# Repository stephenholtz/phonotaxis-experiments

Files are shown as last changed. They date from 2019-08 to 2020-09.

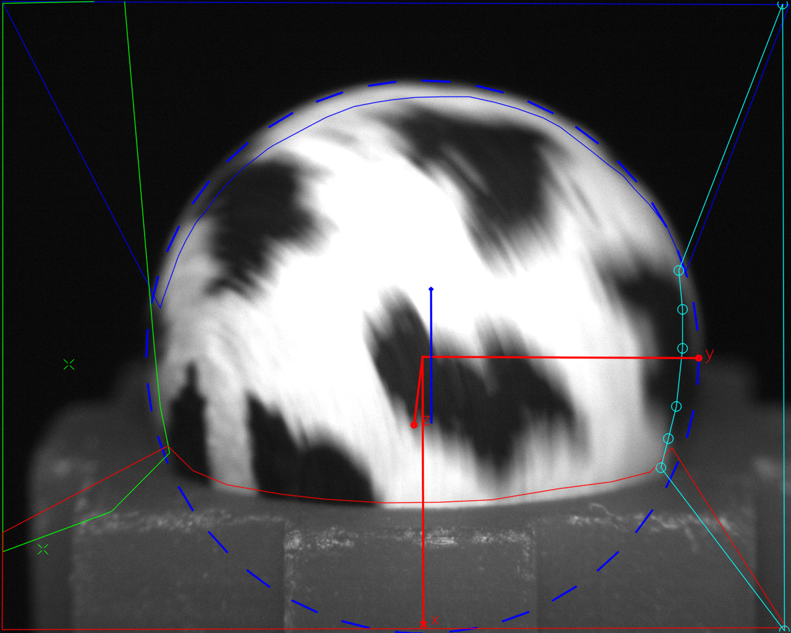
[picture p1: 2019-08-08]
config/fictrac-configImg.png

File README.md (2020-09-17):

phonotaxis-experiments
===
This repository contains code and support files to run a series of phonotaxis experiments. This documentation is quite sparse currently, but `./config` and `./docs` folders contain a large amount of useful information. Additionally, `./literature` has a large number of papers that may be useful to peruse. 

#### Sound Stimuli
There are 8 speakers currently installed in a ring around the center of the rig. Each speaker can be driven independently thanks to an 8 channel sound card. Note that not all speakers are likely able to deliver the same sound field properties to the animal due to some of the optomechanical elements installed to hold hardware. 

#### Cameras
The phonotaxis rig is currently equipped with two cameras. One camera is positioned behind an air supported ball for use with FicTrac offline (or online) tracking. The second camera is positioned above the animal to track additional behavioral responses and kinematic features, for example limb position (e.g. grooming bouts) and antennal movements. 

Since responses can be quite transient, especially at low temporal resolution, dropping frames is a large concern. The system has been stress tested to acquire _at least_ 100fps from both cameras with 2x2 binning using externally sent triggers for each frame from MATALB. The following settings inside of the SpinView GUI or hardware configuration were used. I have roughly categorized the settings to help direct future tinkering.

Hardware Configuration:
- Power both cameras with 12V power supplies directly from FLIR.
- Acquired both via a FLIR (PtGrey) supplied USB3 PCIe card
- Acquired over a FLIR supplied locking USB3.1 cables and active extenders Amazon Basics brand
- Frames written to an NVMI drive 

Triggering Settings to use the optically isolated input to trigger a frame acquisition, and the programmable pin to read out when frame exposures are happening.
- Continusous aquisition mode
- Exposure Mode = timed
- Exposure Auto = Off
- Set the exposure to something that looks good on the display (in units of microseconds)
- Gain Auto = Off
- Trig Sel = frame start
- Trig mode = on
- Trig act = rising
- Trig overlap = read out (not clear this is required)
- Line 2 
	- mode = output 
	- exposure
	- leave inverted unchecked (personal preference)

Acquisition Performance Settings:
- Use Buffered Acquisition
- Buffer Handling Mode should be set to Oldest First (this is very important!!!)
- Set SpinView priority to realtime in Windows 10
- Turn off draw image OR limit the dispayed FPS (settings accessed by right clicking on images)
- Change the Device Link Throuput setting
     - To determine a conservative/valid setting, lower the value until the displayed max FPS decreases in the GUI, then increase it a bit. 
- Bin at 2x (this may not be required)

#### Misc. Notes
- The computer is high performance, so your mileage may vary with older or less powerful machines.

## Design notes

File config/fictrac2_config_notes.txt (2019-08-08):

- Installed CMake
- Visual Studio 2017 Community Edition (needed to jump through many hoops to download) with C++ options selected
- vcpkg downloaded, and "integrated" printed the following afterwards:
	CMake projects should use: "-DCMAKE_TOOLCHAIN_FILE=C:/code/vcpkg/scripts/buildsystems/vcpkg.cmake"
- used vcpkg to install OpenCV, NLopt and Boost::asio packages as described inthe install guide:
	.\vcpkg install opencv[ffmpeg]:x64-windows nlopt:x64-windows boost-asio:x64-windows
	took about 20 mins
- since I am using spinnaker SDK for pointgrey cameras I ran this:
	cmake -G "Visual Studio 15 2017 Win64" -DCMAKE_TOOLCHAIN_FILE=C:/code/vcpkg/scripts/buildsystems/vcpkg.cmake -D PGR_USB3=ON -D PGR_DIR="C:\Program Files\Point Grey Research\Spinnaker" ..
- then to build I used:
	cmake --build . --config Release -j 4

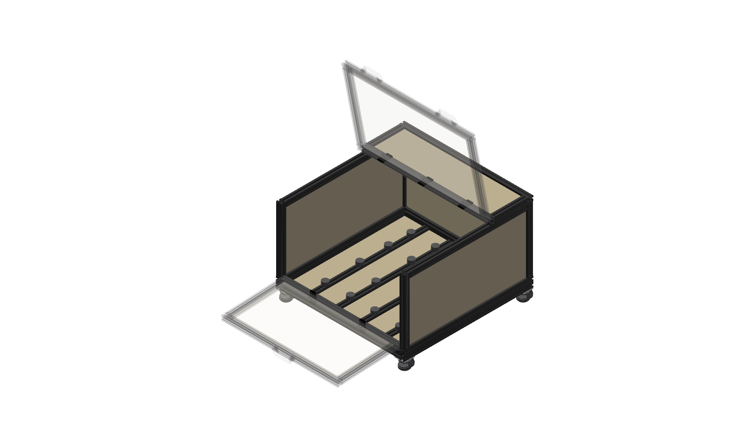
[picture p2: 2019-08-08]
design-files/enclosure/enclosure.png

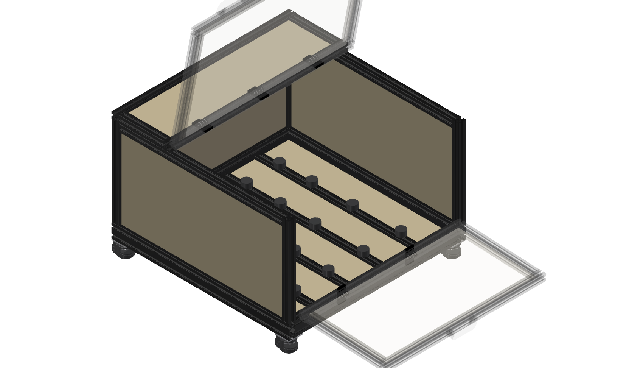
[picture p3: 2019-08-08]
design-files/enclosure/enclosure-zoom.png

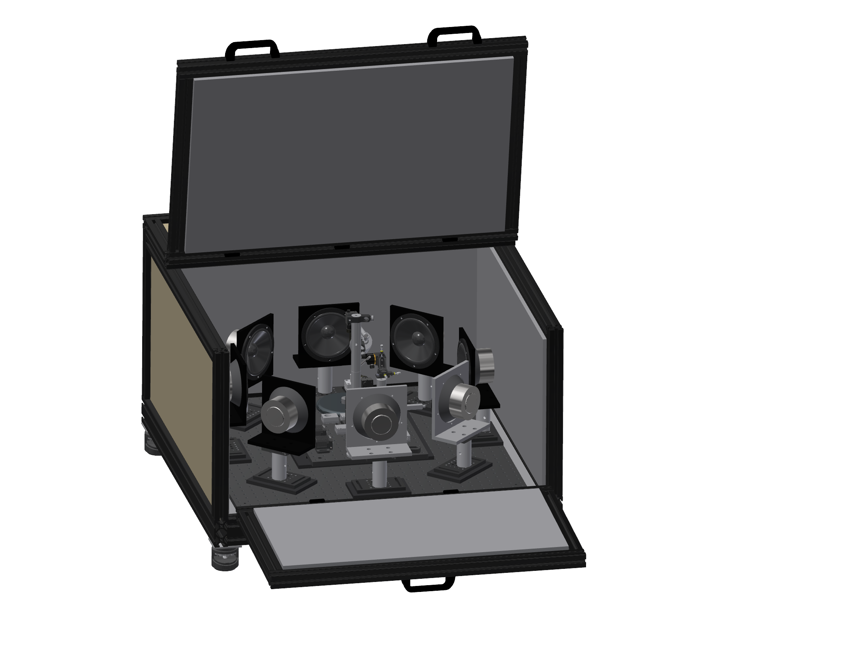
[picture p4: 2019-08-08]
design-files/auditory-behavior-rig.png

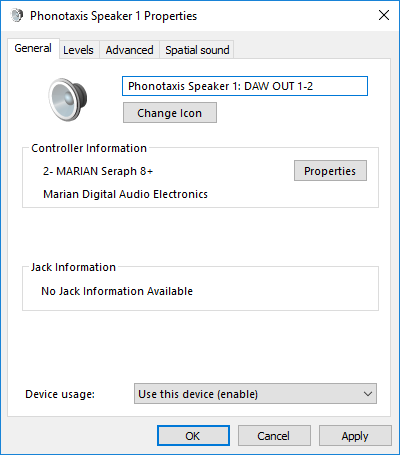
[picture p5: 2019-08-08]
config/speaker_general_windows_properties.png

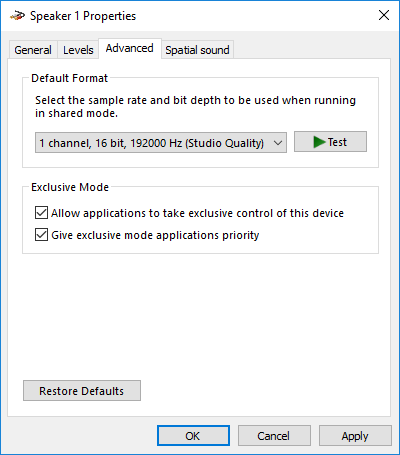
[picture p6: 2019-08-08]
config/speaker_advanced_windows_properties.png

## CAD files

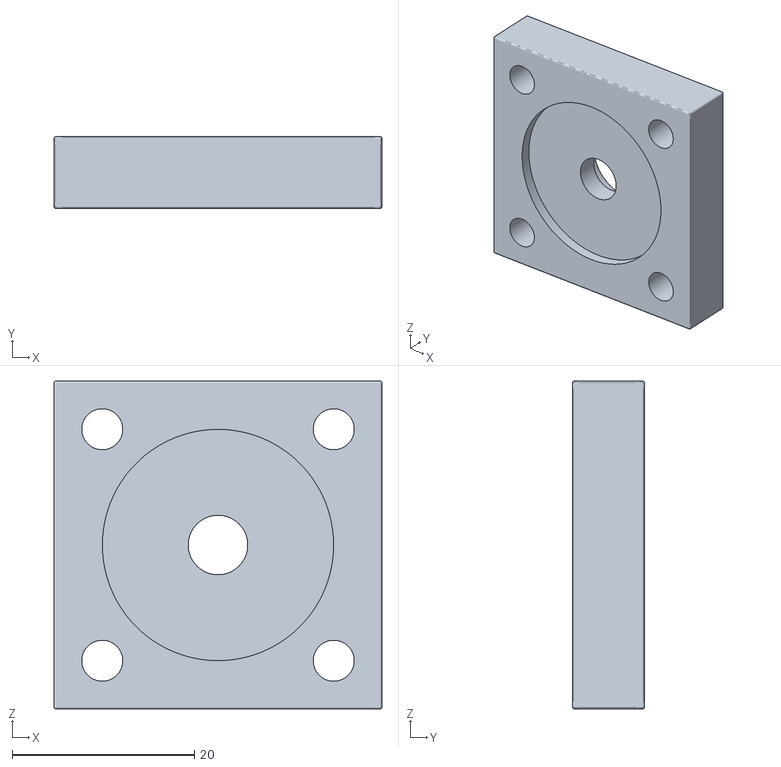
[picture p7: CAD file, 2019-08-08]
design-files/ball-assembly/ball-holder-to-post-adapter.stl
36.0 x 7.94 x 36.0

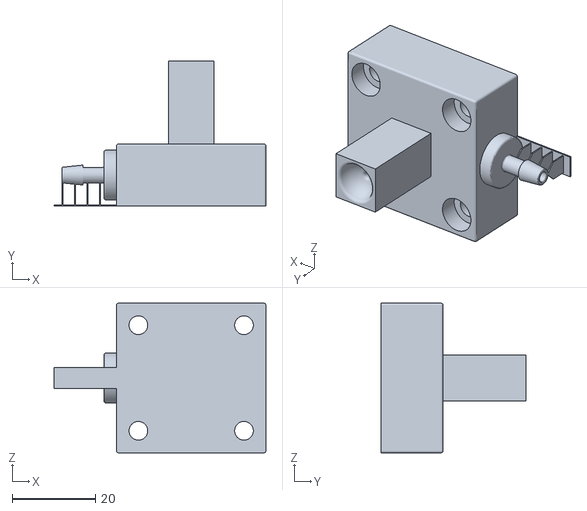
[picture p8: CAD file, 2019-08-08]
design-files/ball-holder/v01_top_square_side_barb_9mm/9mm_ball_holder_v01_manual_supports_mm_high_res.stl
51.0 x 35.0 x 36.0

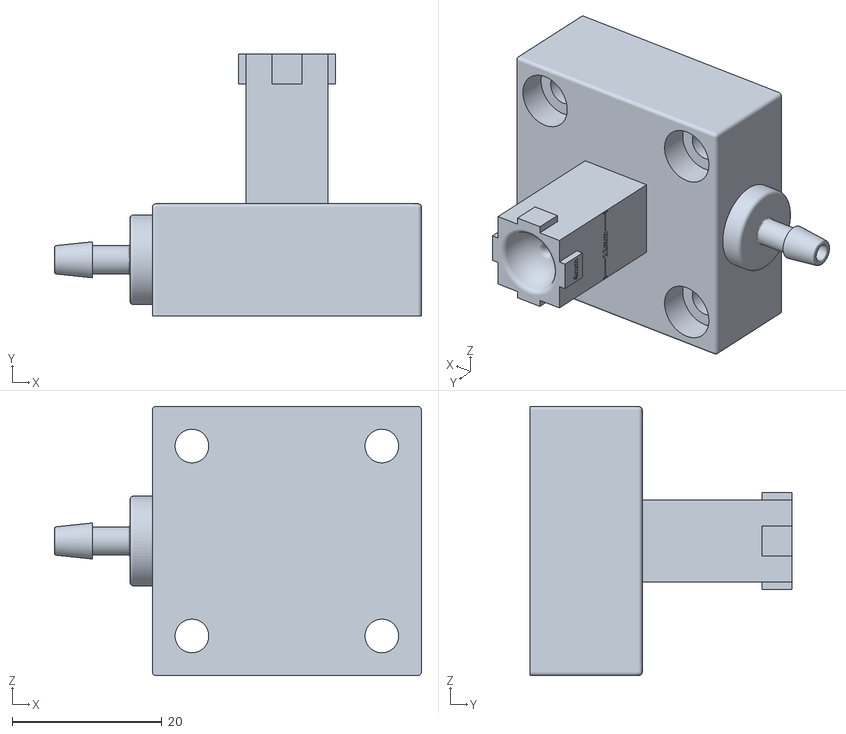
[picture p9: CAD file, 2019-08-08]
design-files/ball-holder/v02_top_side_squares/ball_holder_9mm_sidebarb_v02_mm.stl
49.1 x 35.0 x 36.0

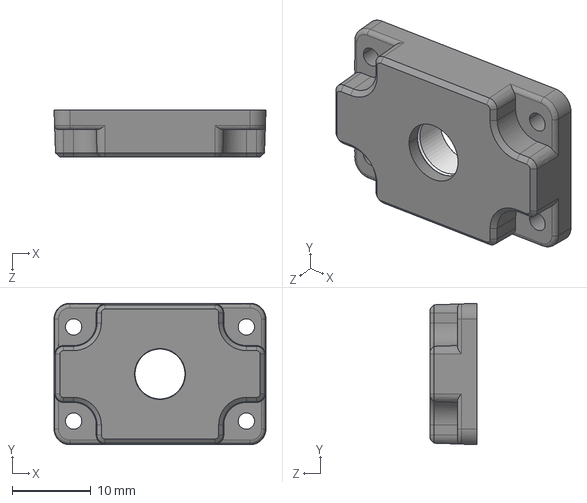
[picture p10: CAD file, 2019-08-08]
design-files/camera-assembly/Flea2 Tripod Adapter.IGS
27.0 x 18.0 x 5.99 mm

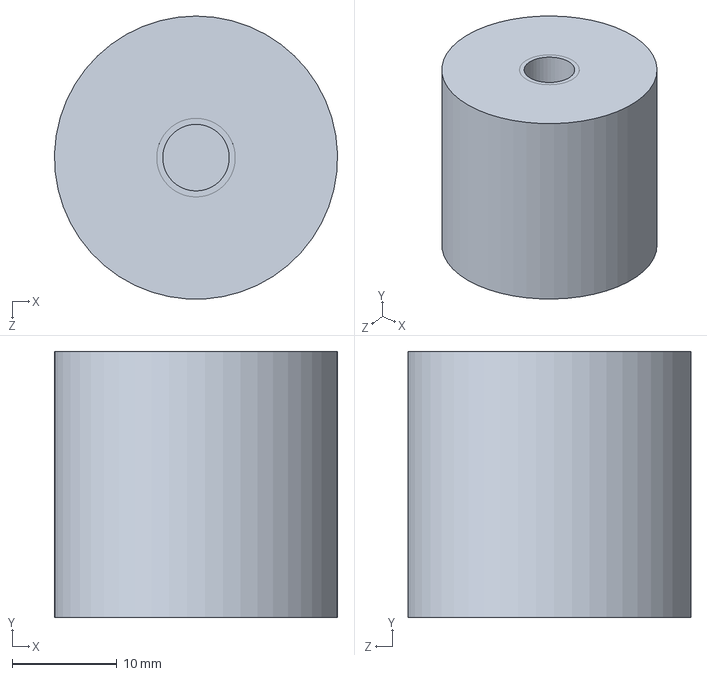
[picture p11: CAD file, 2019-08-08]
design-files/enclosure/AV4-Solidworks.sldprt
27.0 x 25.4 x 27.0 mm

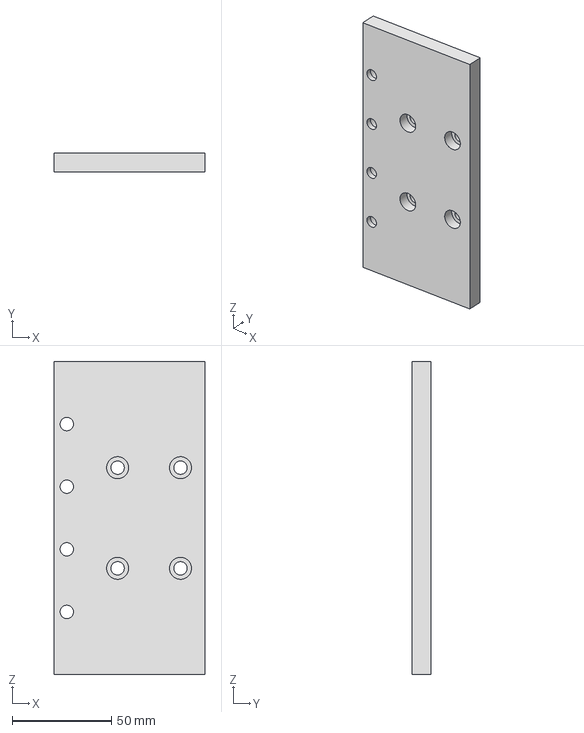
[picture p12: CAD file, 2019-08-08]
design-files/speaker-mount/speaker_mount_base.stp
76.0 x 9.53 x 158.0 mm

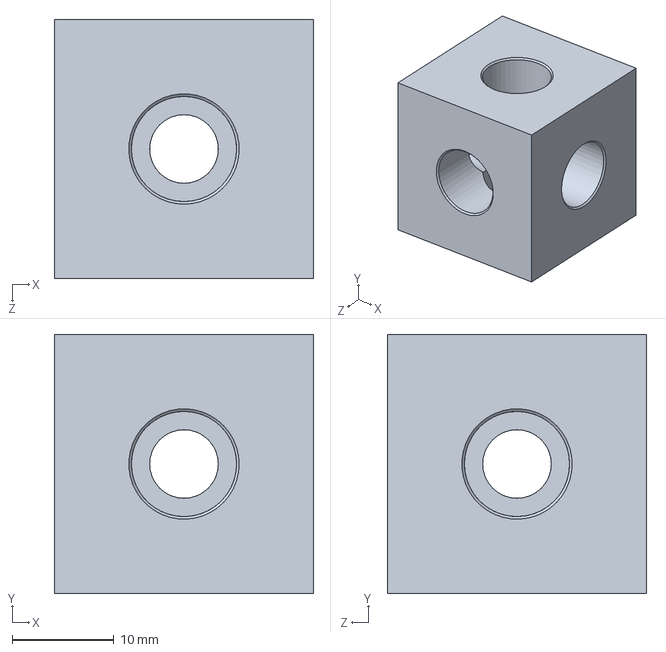
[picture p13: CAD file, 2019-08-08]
design-files/tether-assembly/RM1G-Solidworks.sldprt
25.4 x 25.4 x 25.4 mm

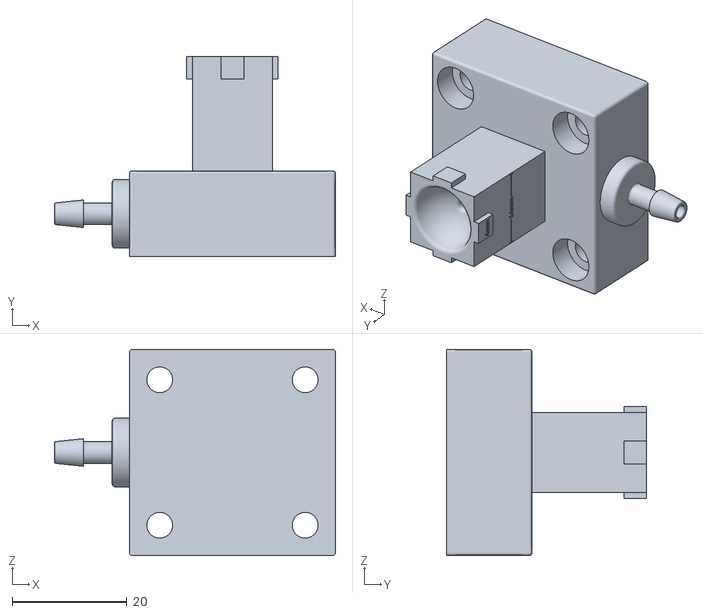
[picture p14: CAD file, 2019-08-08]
design-files/ball-holder/v02_top_side_squares/ball_holder_12mm_sidebarb_v02_mm.stl
49.1 x 35.0 x 36.0

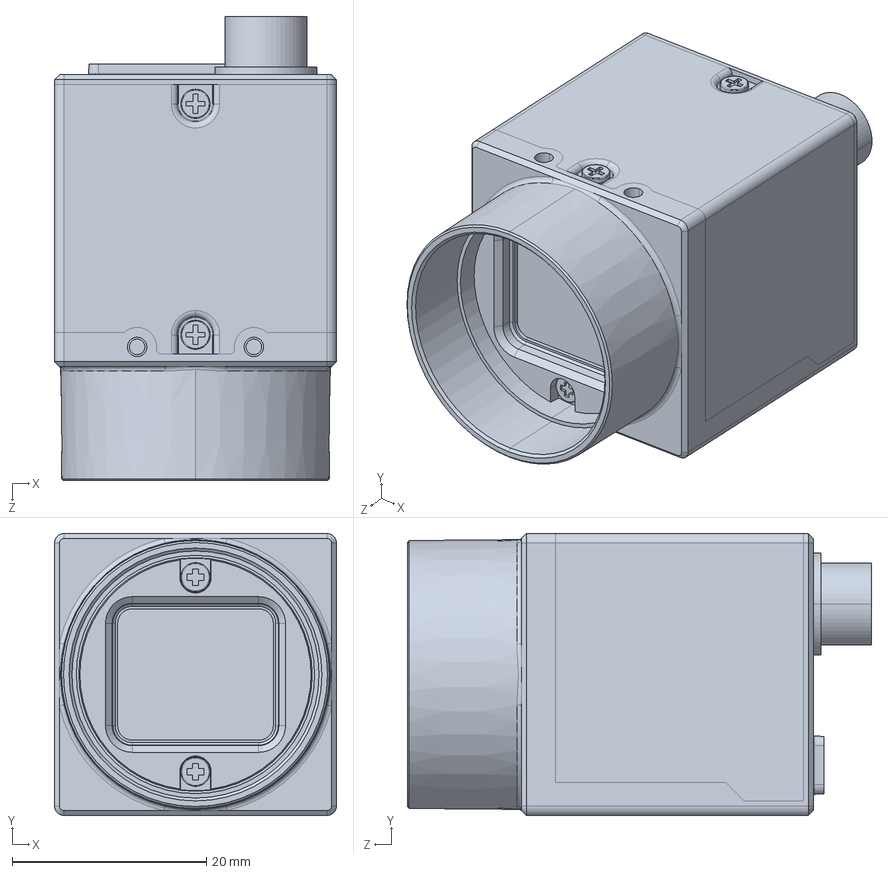
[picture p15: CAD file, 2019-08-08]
design-files/camera-assembly/FL2-020-R0.STEP
29.0 x 29.0 x 47.8 mm

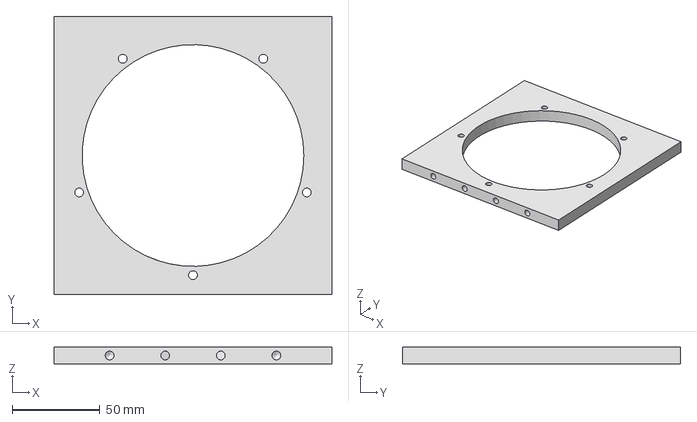
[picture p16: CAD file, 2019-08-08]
design-files/speaker-mount/speaker_mount_face.stp
158.0 x 158.0 x 9.53 mm

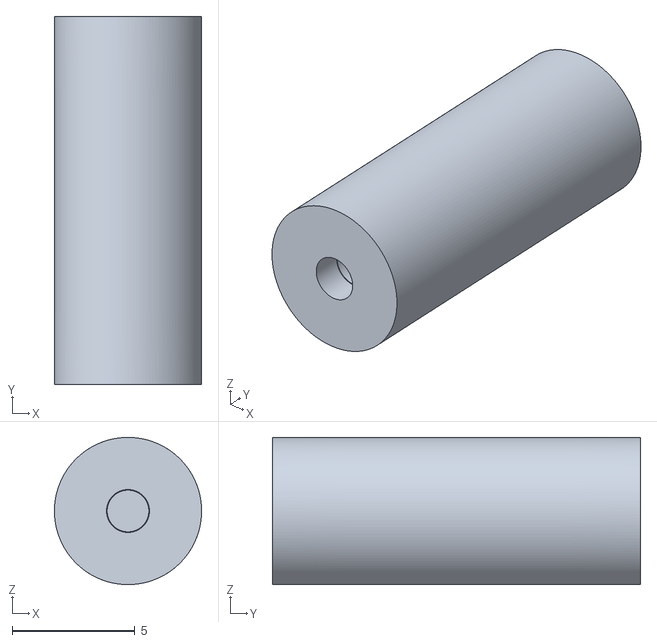
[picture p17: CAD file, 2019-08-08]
design-files/tether-assembly/pin_adapter.stl
6.00 x 15.0 x 6.00

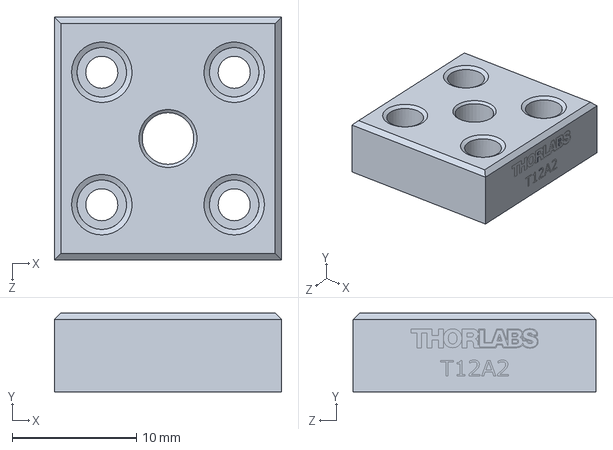
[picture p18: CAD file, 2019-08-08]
design-files/tether-assembly/T12A2-Solidworks.sldprt
18.3 x 6.35 x 19.6 mm

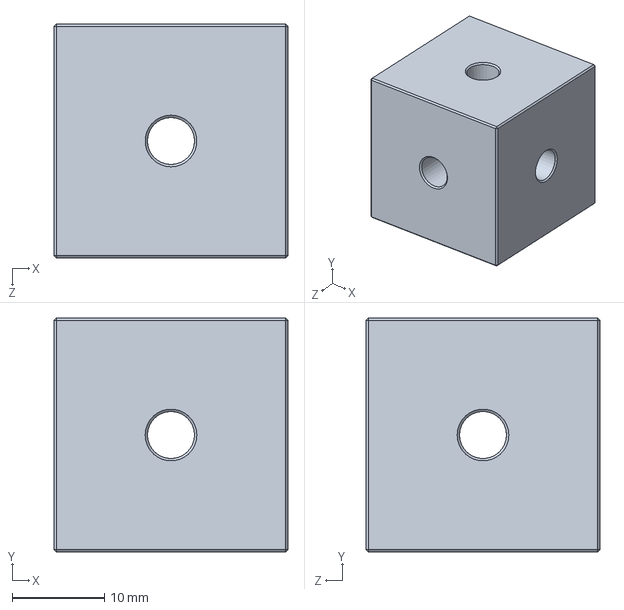
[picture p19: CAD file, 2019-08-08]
design-files/tether-assembly/RM1F-Solidworks.sldprt
25.4 x 25.4 x 25.4 mm

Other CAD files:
design-files/MB30-Solidworks.ipt
design-files/ball-assembly/9mm_ball.ipt
design-files/ball-assembly/BA2-Solidworks.ipt
design-files/ball-assembly/OldVersions/ball-assembly.0018.iam
design-files/ball-assembly/OldVersions/ball-holder-to-post-adapter.0004.ipt
design-files/ball-assembly/ball-assembly.iam
design-files/ball-assembly/ball-holder-to-post-adapter.ipt
design-files/ball-holder/53055K207_BARBED PLASTIC TUBE FITTING.ipt
design-files/ball-holder/9mm_holder_MM_9-68_diameter_Original.ipt
design-files/ball-holder/OldVersions/9mm_ball_holder.0013.ipt
design-files/ball-holder/OldVersions/9mm_ball_holder_manual_supports.0001.ipt
design-files/ball-holder/v01_top_square_side_barb_9mm/9mm_ball_holder_v01.ipt
design-files/ball-holder/v01_top_square_side_barb_9mm/9mm_ball_holder_v01_manual_supports.ipt
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

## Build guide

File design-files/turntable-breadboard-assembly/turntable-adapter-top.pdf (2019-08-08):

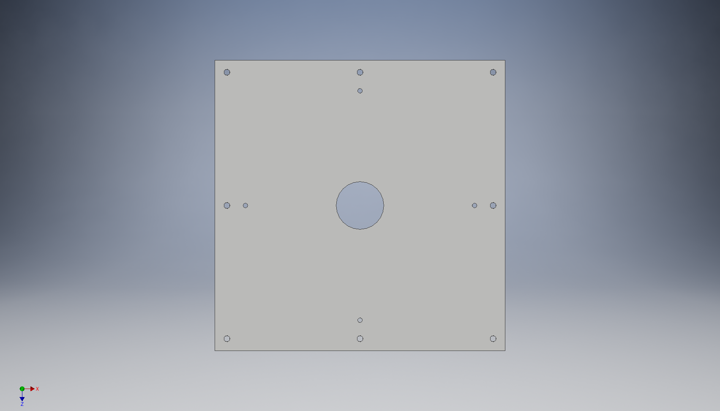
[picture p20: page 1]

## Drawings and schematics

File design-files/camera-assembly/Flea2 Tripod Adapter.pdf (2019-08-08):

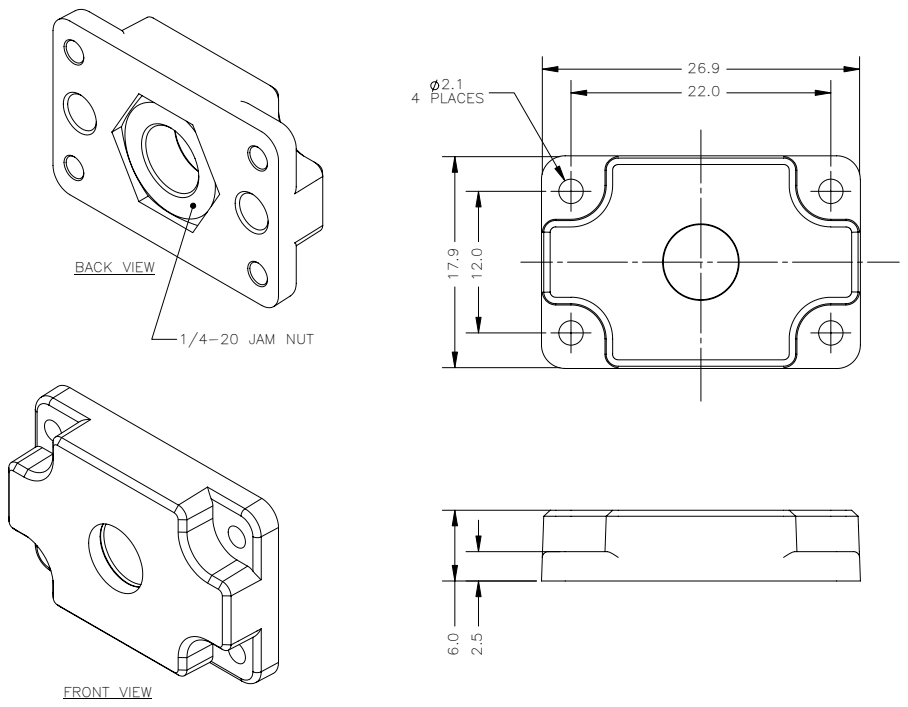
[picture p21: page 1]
2.1 4 PLACES; FRONT VIEW; BACK VIEW; 1/4-20 JAM NUT

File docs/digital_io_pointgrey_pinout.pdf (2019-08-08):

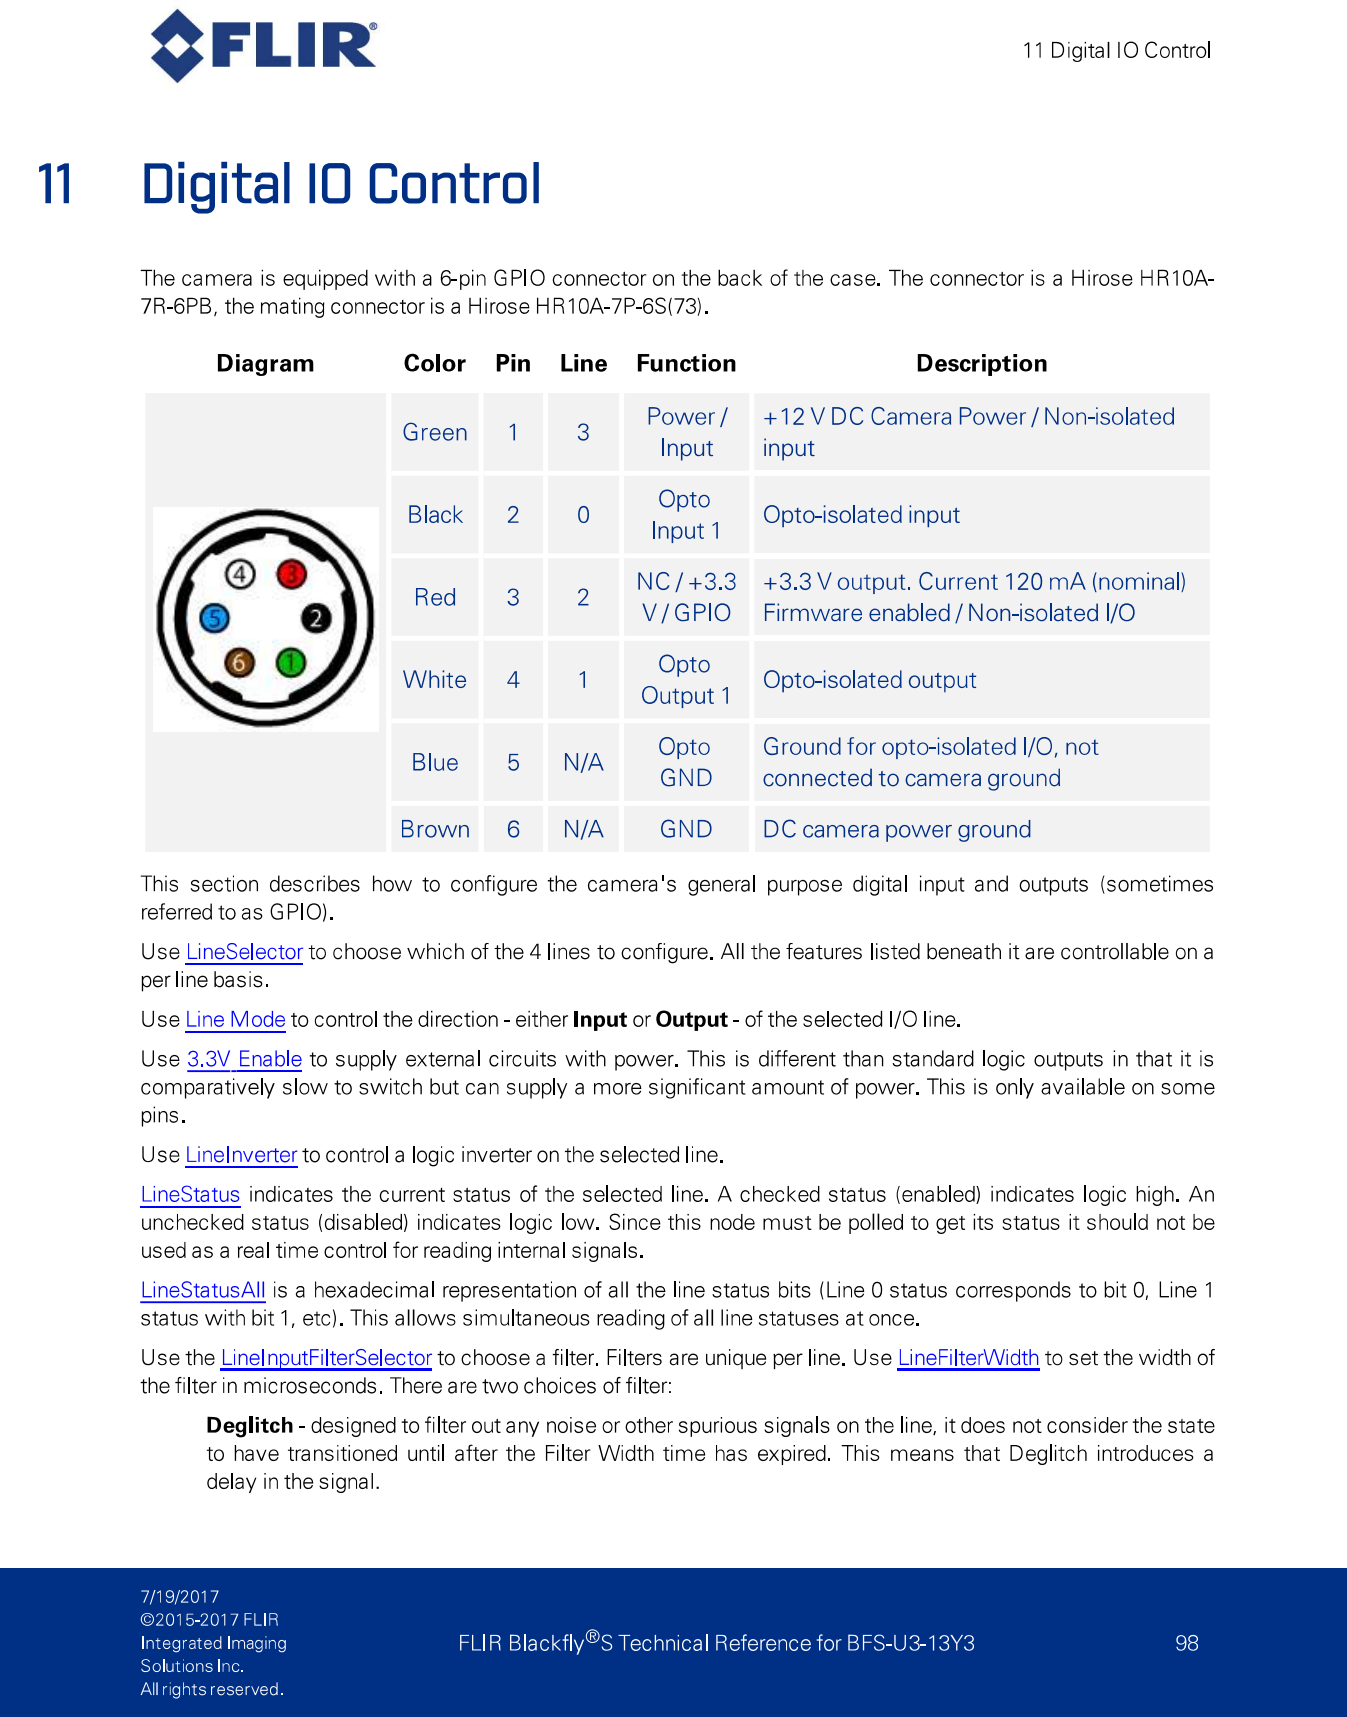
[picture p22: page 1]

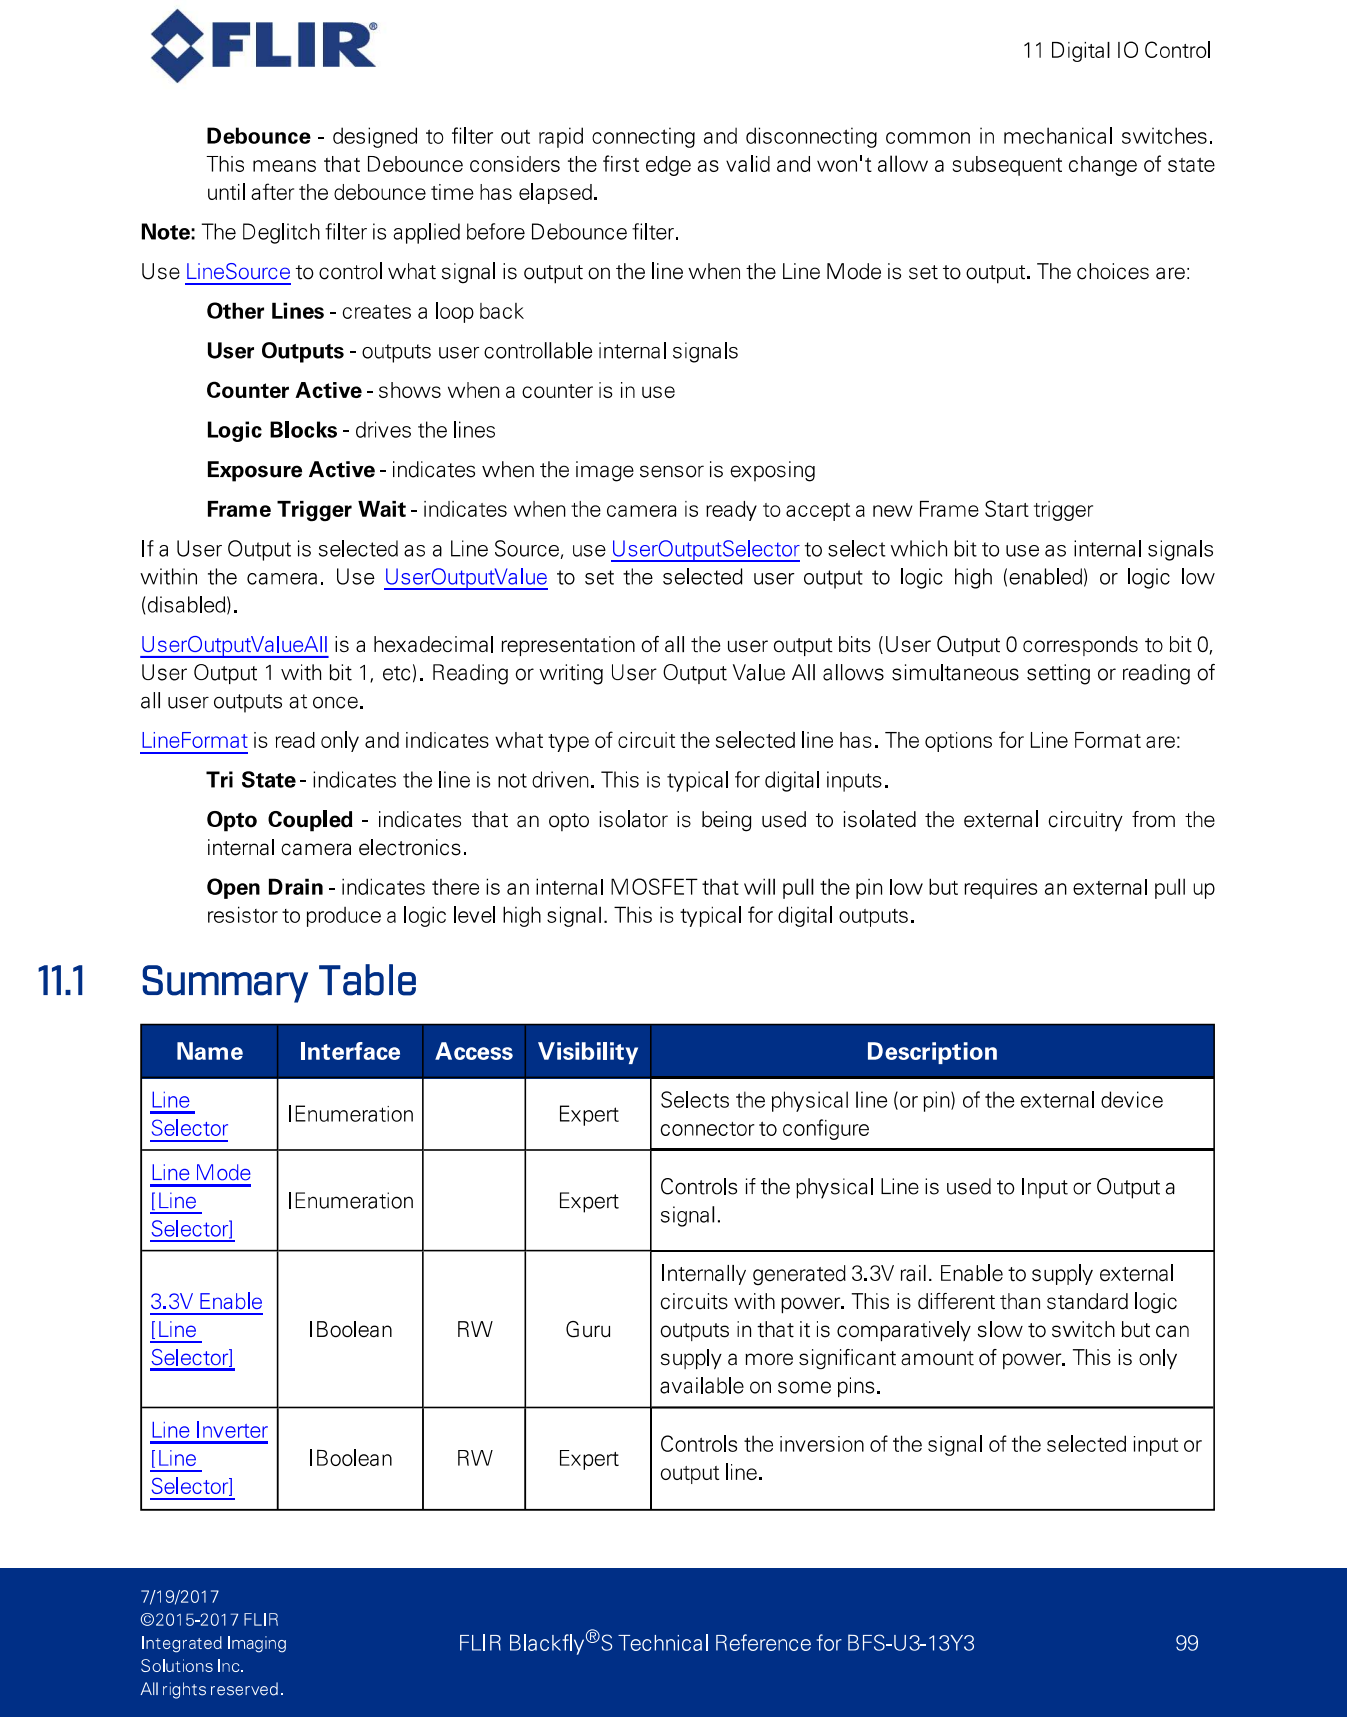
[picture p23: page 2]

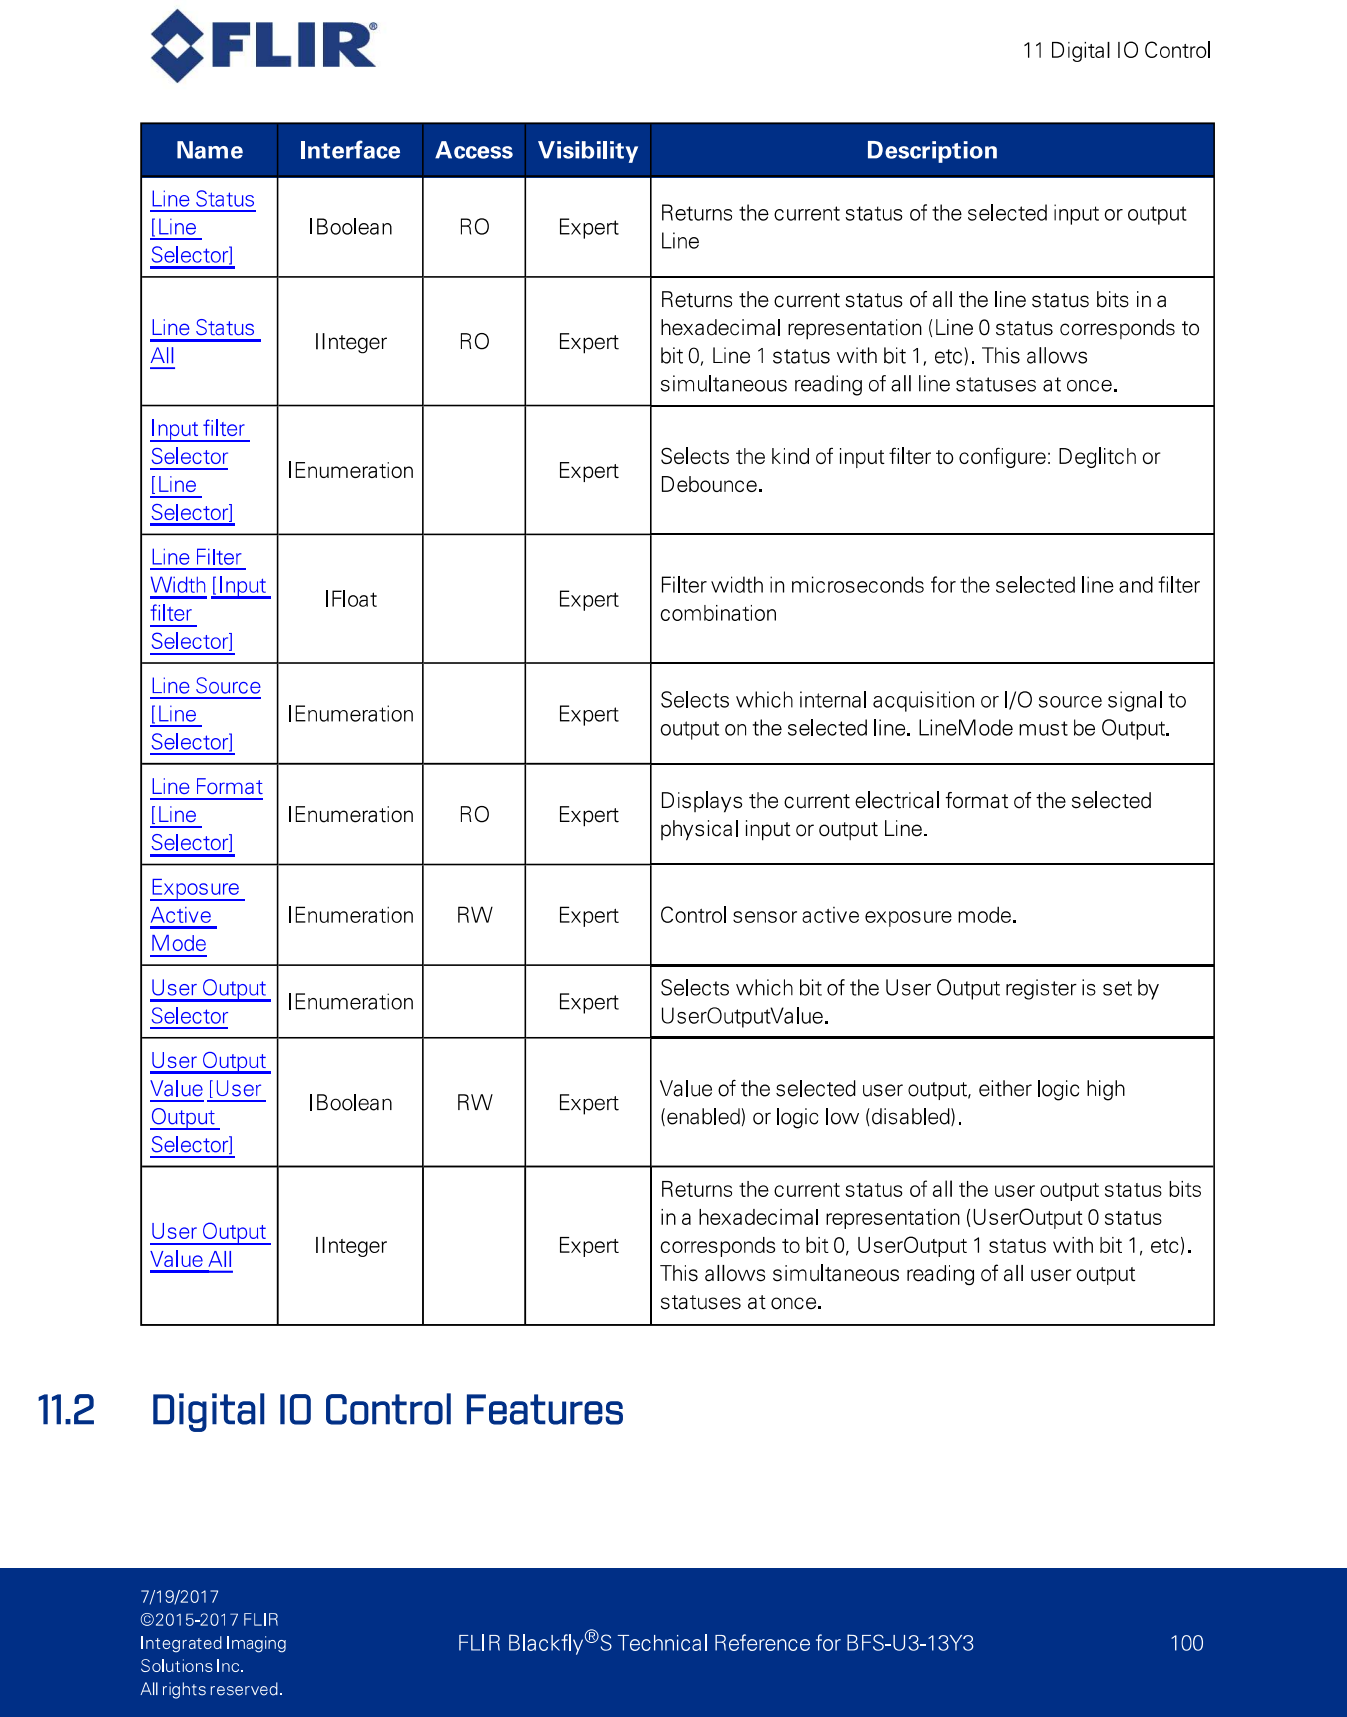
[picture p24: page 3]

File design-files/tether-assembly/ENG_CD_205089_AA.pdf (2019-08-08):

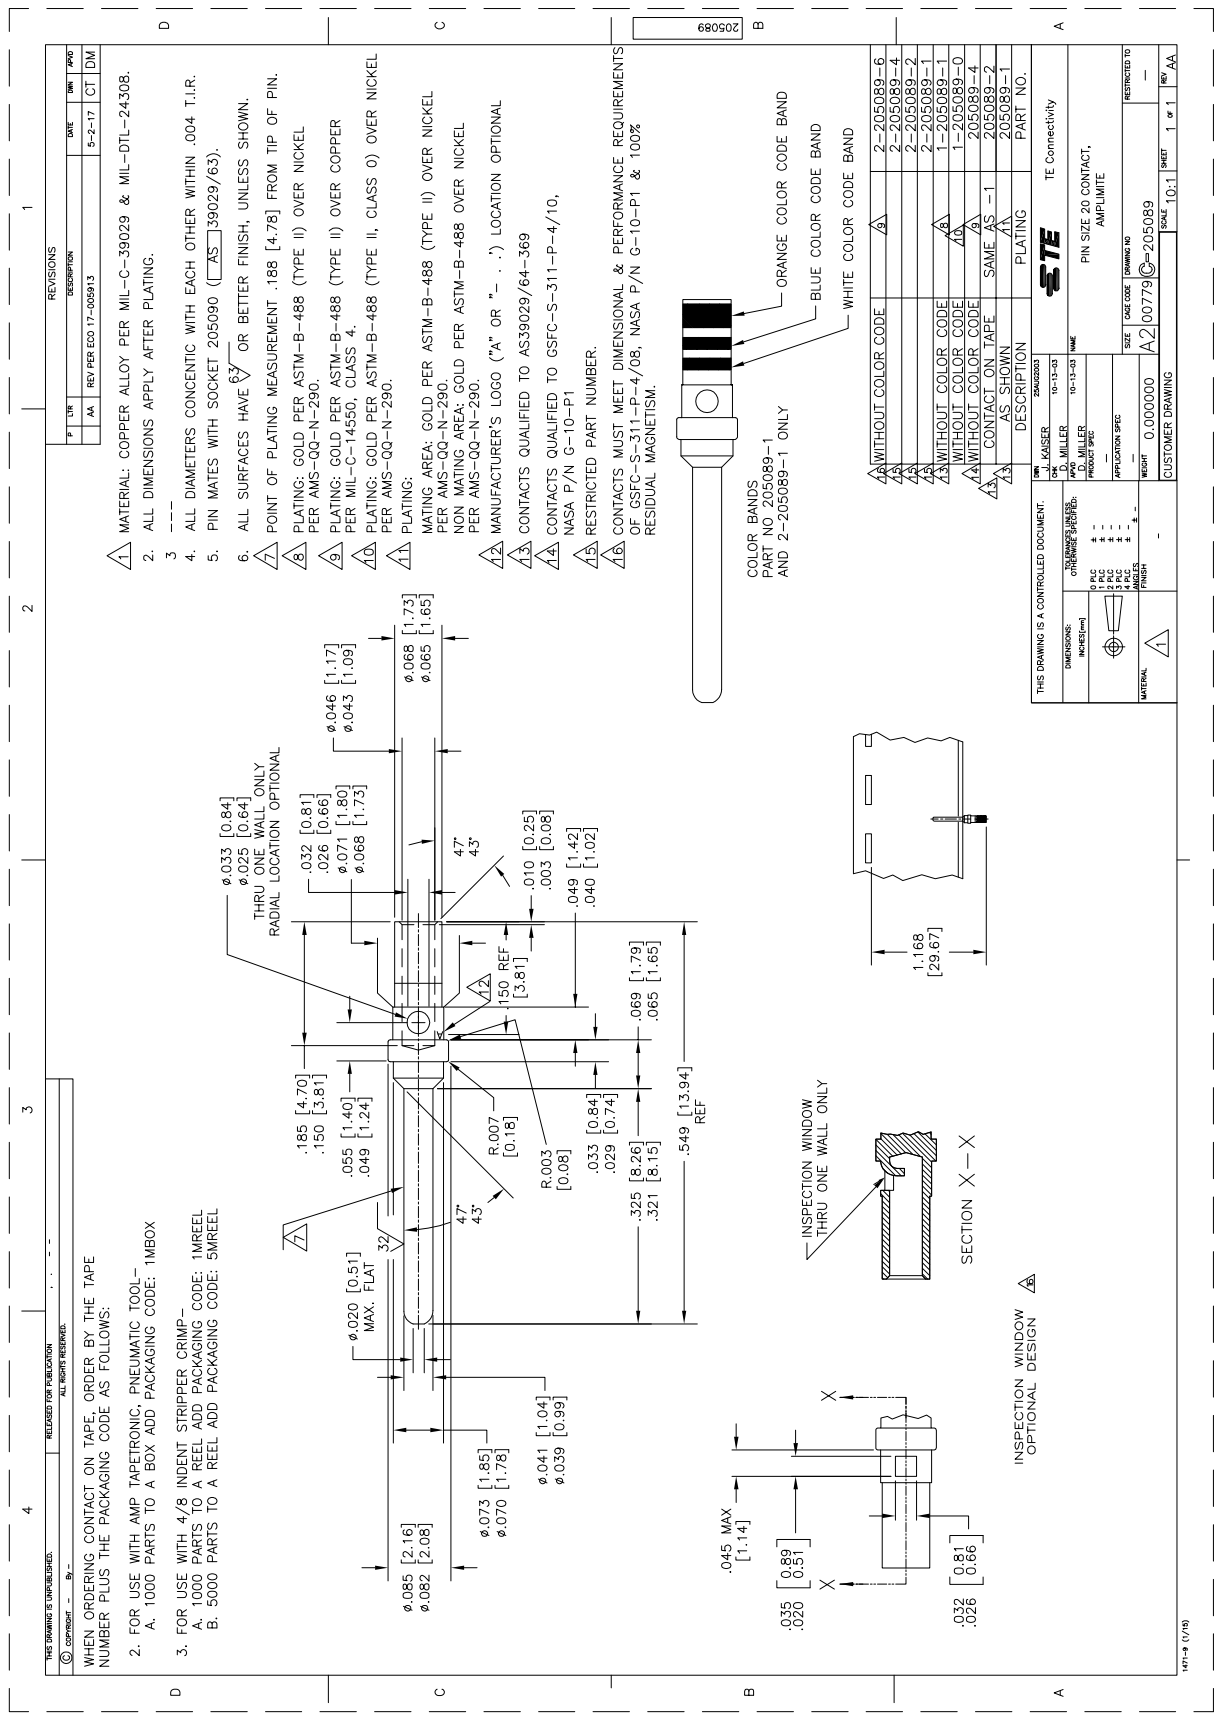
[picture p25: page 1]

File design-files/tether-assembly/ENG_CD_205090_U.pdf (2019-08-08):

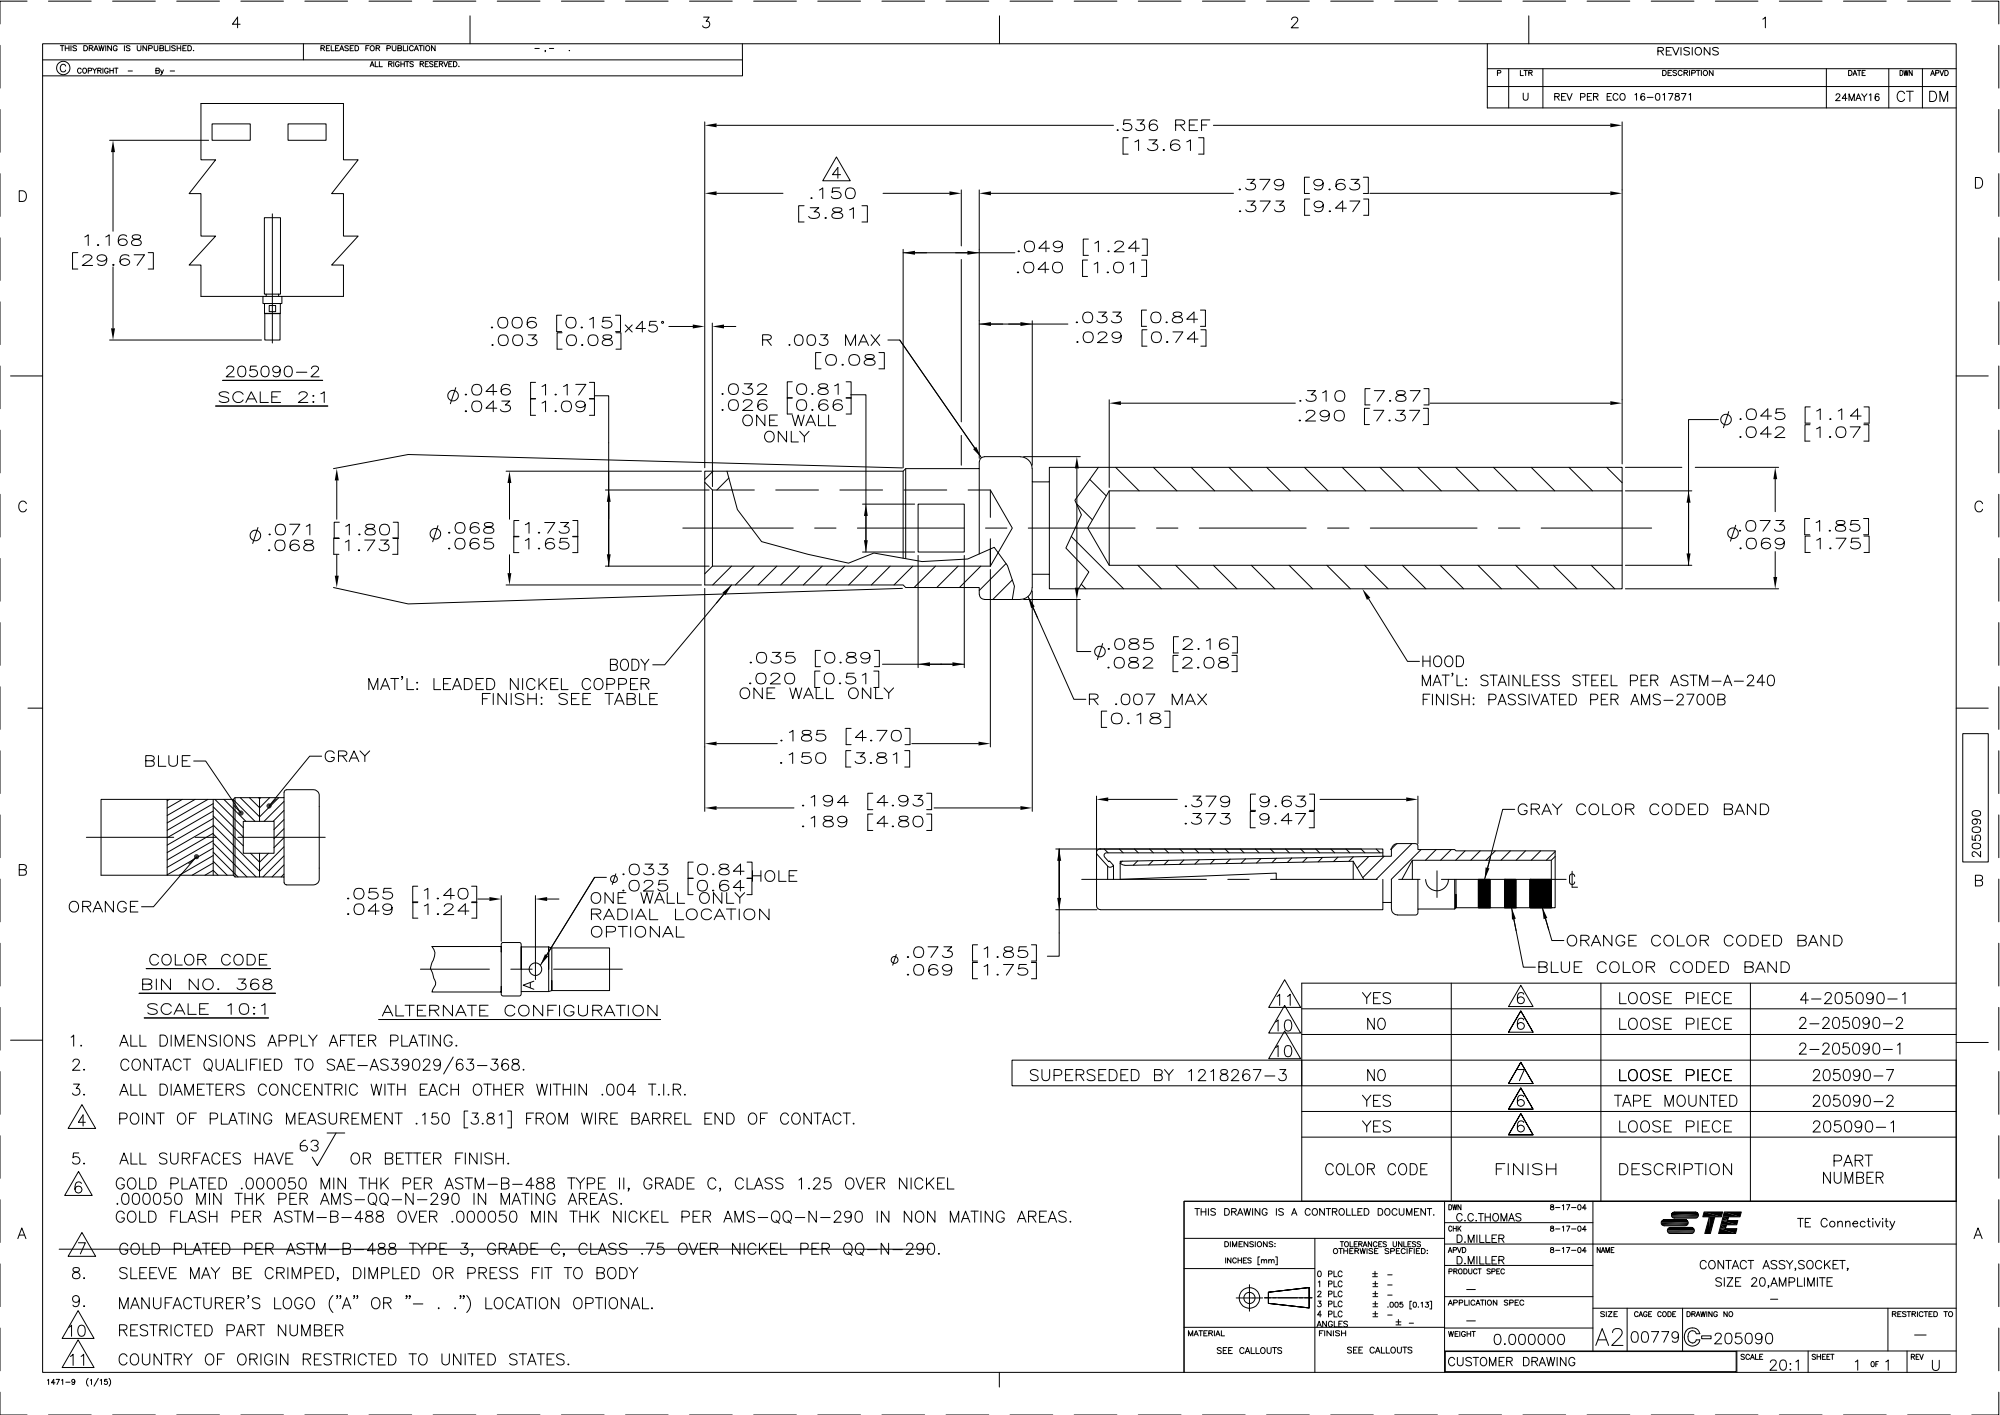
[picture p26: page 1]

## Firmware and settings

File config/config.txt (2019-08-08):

## FicTrac config file (build Jun 25 2019)
c2a_cnrs_xy      : { 120, 578, 1168, 574, 1270, 890, 117, 907 }
c2a_cnrs_yz      : { 200, 580, 1208, 581, 1210, 842, 134, 834 }
c2a_r            : { 2.075312, 2.076196, 0.226109 }
c2a_src          : c2a_cnrs_yz
c2a_t            : { 0.046030, 0.188689, 125.037134 }
do_display       : y
max_bad_frames   : -1
opt_bound        : 0.35
opt_do_global    : n
opt_max_err      : -1.000000
opt_max_evals    : 50
opt_tol          : 0.001
out_port         : -1
q_factor         : 8
roi_c            : { 0.000286, 0.000427, 1.000000 }
roi_circ         : { 324, 308, 962, 220, 662, 128, 272, 405, 867, 178, 1130, 594 }
roi_ignr         : { { 3, 2, 1277, 7, 1110, 438, 1079, 367, 1050, 330, 1027, 306, 1008, 284, 980, 263, 958, 245, 932, 225, 906, 205, 878, 190, 836, 175, 800, 165, 759, 156, 715, 156, 672, 157, 634, 161, 608, 165, 572, 172, 528, 189, 505, 201, 477, 216, 443, 234, 432, 241, 417, 253, 397, 268, 377, 287, 351, 315, 335, 338, 317, 359, 300, 389, 288, 414, 276, 448, 268, 470, 262, 487, 259, 498 }, { 201, 1, 249, 559, 259, 658, 274, 732, 180, 827, 4, 892, 4, 5 }, { 271, 721, 312, 761, 368, 784, 455, 799, 525, 807, 621, 813, 710, 812, 796, 808, 904, 790, 989, 779, 1052, 763, 1087, 724, 1272, 1015, 3, 1018, 4, 861 }, { 1098, 437, 1104, 500, 1104, 563, 1094, 657, 1081, 709, 1069, 756, 1269, 1020, 1266, 6 } }
roi_r            : 0.002949
save_debug       : n
save_raw         : n
src_fn           : 0
src_fps          : -1.000000
thr_ratio        : 1.25
thr_win_pc       : 0.25
vfov             : .387
vid_codec        : h264
